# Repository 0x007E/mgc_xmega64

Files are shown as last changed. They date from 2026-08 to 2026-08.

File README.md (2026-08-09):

  

# `MGC_module` - ATxmega64

The `ATxmega64` (`mgc_module`) is an adaptable board for the [MeGARCard](https://github.com/0x007e/mgc). The board offers the possibility to control the `MeGARCard` with an [ATxmega64](#additional-information). The board itself is connected to the `MeGARCard` within the pcb-to-pcb connectors (no soldering necessary). With the onboard dip-switches the reset can be enabled/disabled for `PDI` programming.

> To mount the board on the `MeGARCard` disconnect the power source (`USB-C` connector) or any other used source from the MeGARCard!

| Experience  | Level |
|:---|:---:|
| Soldering | ?% |

# Downloads

| Type | File | Description |
|:---:|:---:|:---|
| Schematic | [pdf](https://github.com/0x007E/mgc_xmega64/releases/latest/download/schematic.pdf) / [cadlab](https://cadlab.io/project/30510/main/files) | Schematic files |
| Board | [pdf](https://github.com/0x007E/mgc_xmega64/releases/latest/download/pcb.pdf) / [cadlab](https://cadlab.io/project/30510/main/files) | Board file |
| Drill | [pdf](https://github.com/0x007E/mgc_xmega64/releases/latest/download/drill.pdf) | Drill file |
| BoM | [xlsx](https://github.com/0x007E/mgc_xmega64/releases/latest/download/bom.xlsx) / [html](https://github.com/0x007E/mgc_xmega64/releases/latest/download/ibom.html) | Bill of Material as Excel/interactive HTML |
| PCB | [zip](https://github.com/0x007E/mgc_xmega64/releases/latest/download/kicad.zip) / [tar](https://github.com/0x007E/mgc_xmega64/releases/latest/download/kicad.tar.gz) | KiCAD/Gerber/BoM/Drill files |

# Hardware

The pcb is created with `KiCAD`. All files are built with `github actions` so that they are ready for a production environment.

## PCB

The circuit board is populated on both sides (Top, Bottom). The best way for soldering the `SMD` components is within a vapor phase soldering system and for the `THT` components with a standard soldering system.

### Top Layer

Top Layer

### Bottom Layer

Bottom Layer

# Additional Information

| Type | Link | Description |
|:---:|:---:|:---|
| ATxmega64  | [pdf](https://ww1.microchip.com/downloads/en/DeviceDoc/ATxmega128-64-32-16A4U-DataSheet-DS40002166A.pdf) | ATxmega16/32/64/128 Data Sheet |

---

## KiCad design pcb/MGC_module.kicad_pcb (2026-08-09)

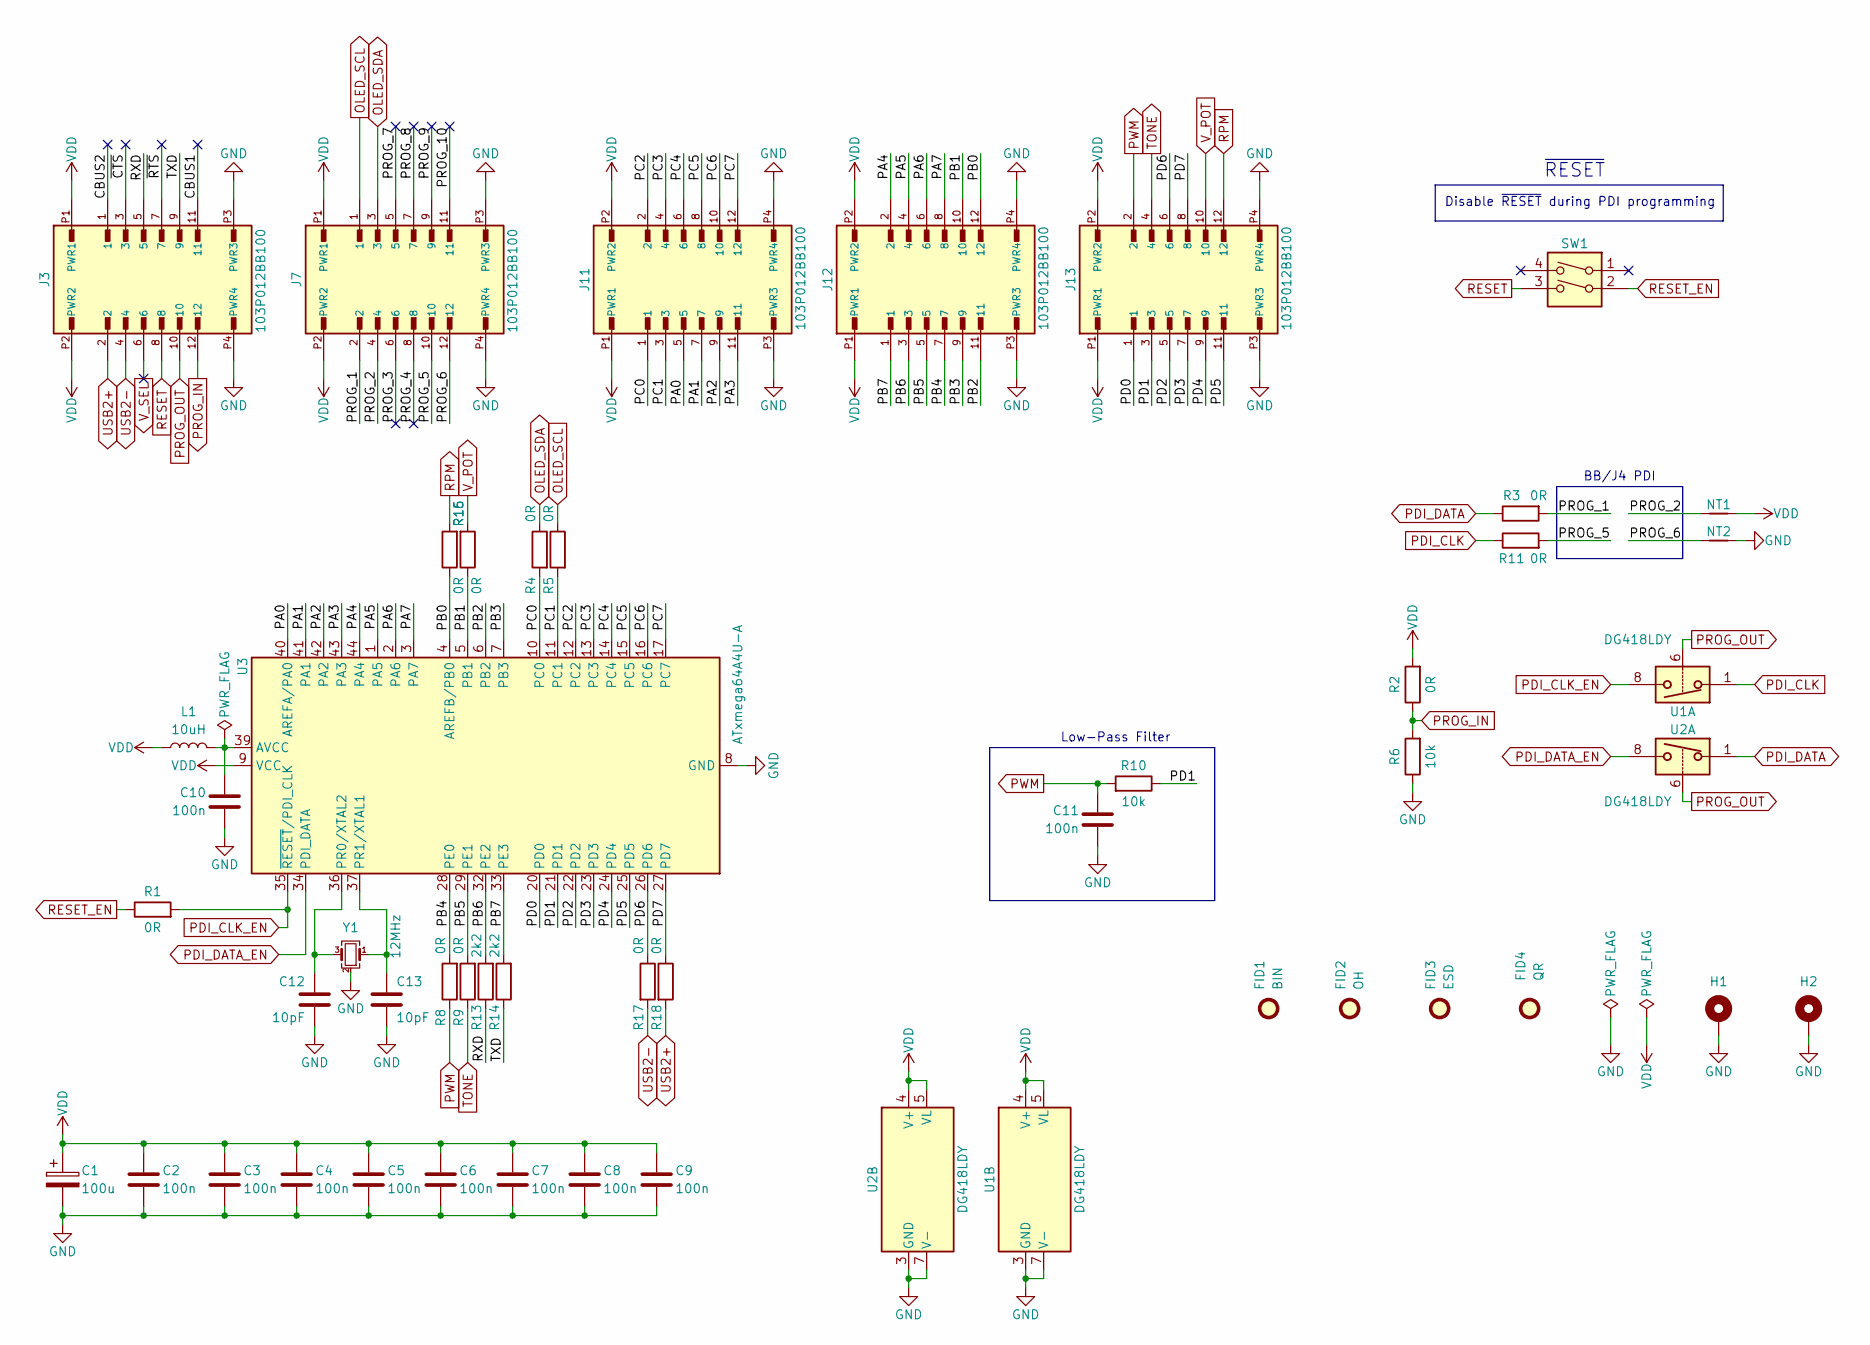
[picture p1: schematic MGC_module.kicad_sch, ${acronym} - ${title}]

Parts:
C1: 100u; CP_EIA-3528-21_Kemet-B; DigiKey 478-3877-1-ND
C2, C3, C4, C5, C6, C7, C8, C9, C10, C11: 100n; C_1206_3216Metric
C12, C13: 10pF; C_0603_1608Metric
FID1: BIN; WEEE-Logo_4.2x6mm_SilkScreen
FID2: OH; OSHW-Logo2_7.3x6mm_SilkScreen
FID3: ESD; ESD-Logo_6.6x6mm_SilkScreen
FID4: QR; QR_0x007e_very_small
H1, H2: MountingHole_Pad; MountingHole_2.7mm_M2.5_DIN965_Pad
J3, J7, J11, J12, J13: 103P012BB100; AMPHENOL_103P012BB100; DigiKey 609-103P012BB100CT-ND
L1: 10uH; L_1206_3216Metric
NT1, NT2: NetTie_2; NetTie-2_SMD_Pad0.5mm
R1, R2, R3, R4, R5, R8, R9, R11, R15, R16: 0R; R_1206_3216Metric
R6, R10: 10k; R_1206_3216Metric
R13, R14: 2k2; R_1206_3216Metric
R17, R18: 0R; R_0603_1608Metric; DigiKey CR0603AJ/-000EASCT-ND
SW1: SW_DIP_x02; SW_DIP_SPSTx02_Slide_6.7x6.64mm_W6.73mm_P2.54mm_LowProfile_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
U1, U2: DG418LDY; SOIC-8_3.9x4.9mm_P1.27mm; DigiKey DG417LEDY-T1-GE4CT-ND
U3: ATxmega64A4U-A; TQFP-44_10x10mm_P0.8mm; DigiKey ATXMEGA64A4U-AU-ND
Y1: 12MHz; Crystal_SMD_Abracon_ABM8AIG-4Pin_3.2x2.5mm

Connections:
/CBUS1: J3.11
/CBUS2: J3.1
/PA0: J11.5, U3.40 (AREFA/PA0)
/PA1: J11.7, U3.41 (PA1)
/PA2: J11.9, U3.42 (PA2)
/PA3: J11.11, U3.43 (PA3)
/PA4: J12.2, U3.44 (PA4)
/PA5: J12.4, U3.1 (PA5)
/PA6: J12.6, U3.2 (PA6)
/PA7: J12.8, U3.3 (PA7)
/PB0: J12.12, R15.1, U3.4 (AREFB/PB0)
/PB1: J12.10, R16.1, U3.5 (PB1)
/PB2: J12.11, U3.6 (PB2)
/PB3: J12.9, U3.7 (PB3)
/PB4: J12.7, R8.2, U3.28 (PE0)
/PB5: J12.5, R9.2, U3.29 (PE1)
/PB6: J12.3, R13.2, U3.32 (PE2)
/PB7: J12.1, R14.2, U3.33 (PE3)
/PC0: J11.1, R4.2, U3.10 (PC0)
/PC1: J11.3, R5.2, U3.11 (PC1)
/PC2: J11.2, U3.12 (PC2)
/PC3: J11.4, U3.13 (PC3)
/PC4: J11.6, U3.14 (PC4)
/PC5: J11.8, U3.15 (PC5)
/PC6: J11.10, U3.16 (PC6)
/PC7: J11.12, U3.17 (PC7)
/PD0: J13.1, U3.20 (PD0)
/PD1: J13.3, R10.1, U3.21 (PD1)
/PD2: J13.5, U3.22 (PD2)
/PD3: J13.7, U3.23 (PD3)
/PD4: J13.9, U3.24 (PD4)
/PD5: J13.11, U3.25 (PD5)
/PD6: J13.6, R17.1, U3.26 (PD6)
/PD7: J13.8, R18.1, U3.27 (PD7)
/PROG_1: J7.2, R3.2
/PROG_2: J7.4, NT1.1
/PROG_3: J7.6
/PROG_4: J7.8
/PROG_5: J7.10, R11.2
/PROG_6: J7.12, NT2.1
/PROG_7: J7.5
/PROG_8: J7.7
/PROG_9: J7.9
/PROG_10: J7.11
/RXD: J3.5, R13.1
/TXD: J3.9, R14.1
/~CTS: J3.3
/~RTS: J3.7
GND: C1.2, C2.2, C3.2, C4.2, C5.2, C6.2, C7.2, C8.2, C9.2, C10.2, C11.2, C12.2, C13.2, H1.1, H2.1, J3.P3 (PWR3), J3.P4 (PWR4), J7.P3 (PWR3), J7.P4 (PWR4), J11.P3 (PWR3), J11.P4 (PWR4), J12.P3 (PWR3), J12.P4 (PWR4), J13.P3 (PWR3), J13.P4 (PWR4), NT2.2, R6.1, U1.3 (GND), U1.7 (V-), U2.3 (GND), U2.7 (V-), U3.8 (GND), U3.18 (GND), U3.30 (GND), U3.38 (GND), Y1.2 (G), Y1.4 (G)
unnamed: C10.1, L1.2, U3.39 (AVCC)
unnamed: C12.1, U3.36 (PR0/XTAL2), Y1.3
unnamed: C13.1, U3.37 (PR1/XTAL1), Y1.1
OLED_SCL: J7.1, R5.1
OLED_SDA: J7.3, R4.1
PDI_CLK: R11.1, U1.1
PDI_CLK_EN: R1.2, U1.8, U3.35 (~RESET/PDI_CLK)
PDI_DATA: R3.1, U2.1
PDI_DATA_EN: U2.8, U3.34 (PDI_DATA)
PROG_IN: J3.12, R2.1, R6.2
PROG_OUT: J3.10, U1.6, U2.6
PWM: C11.1, J13.2, R8.1, R10.2
RESET: J3.8, SW1.3
RESET_EN: R1.1, SW1.2
RPM: J13.12, R15.2
TONE: J13.4, R9.1
USB2+: J3.2, R18.2
USB2-: J3.4, R17.2
VDD: C1.1, C2.1, C3.1, C4.1, C5.1, C6.1, C7.1, C8.1, C9.1, J3.P1 (PWR1), J3.P2 (PWR2), J7.P1 (PWR1), J7.P2 (PWR2), J11.P1 (PWR1), J11.P2 (PWR2), J12.P1 (PWR1), J12.P2 (PWR2), J13.P1 (PWR1), J13.P2 (PWR2), L1.1, NT1.2, R2.2, U1.4 (V+), U1.5 (VL), U2.4 (V+), U2.5 (VL), U3.9 (VCC), U3.19 (VCC), U3.31 (VCC)
V_POT: J13.10, R16.2
V_SEL: J3.6

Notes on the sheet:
Disable ~{RESET} during PDI programming
Low-Pass Filter
BB/J4 PDI
~{RESET}

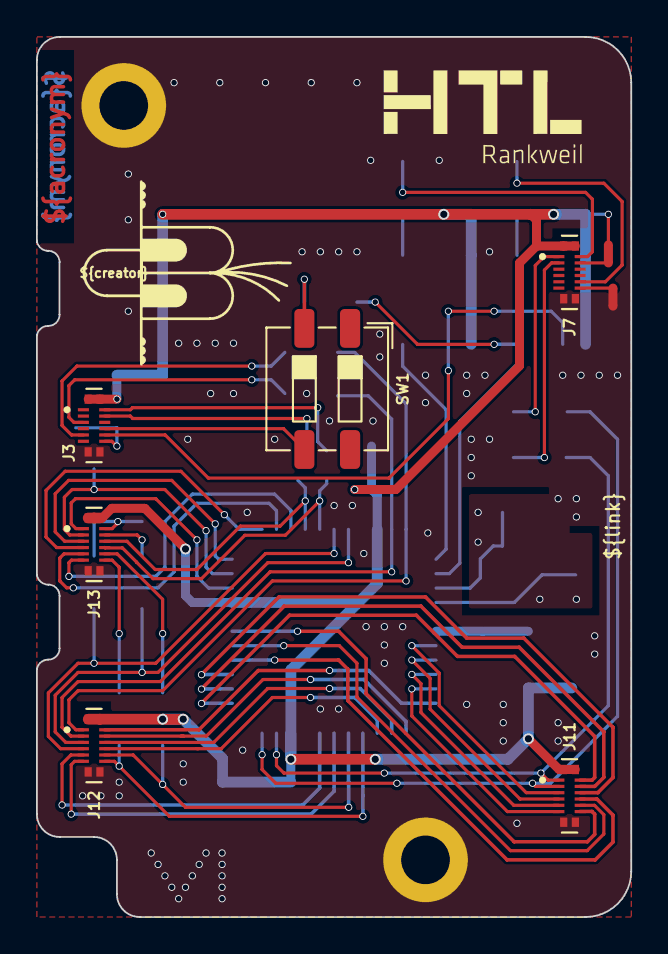
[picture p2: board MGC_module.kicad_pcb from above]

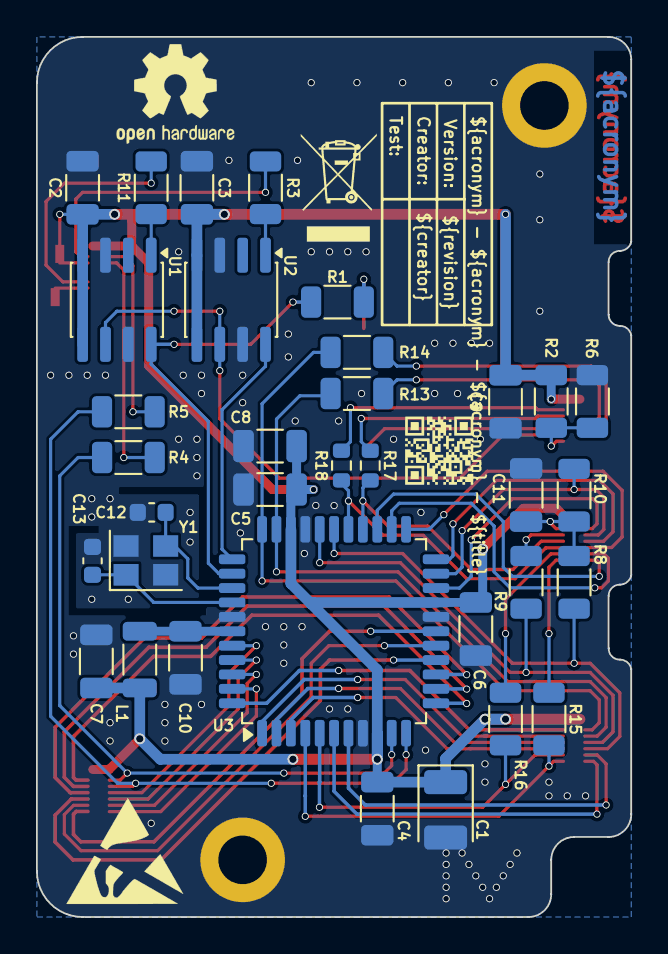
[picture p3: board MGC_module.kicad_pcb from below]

Board: 2 copper layers, 33.0 x 48.9 mm, 48 parts (38 on the bottom side), 59 nets.

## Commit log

2026-08-09 Add pcb layout
    [MGC_module.kicad_pcb, MGC_module.kicad_sch]
2026-08-09 Optimize fabrication layer
    [MGC_module.kicad_pcb]

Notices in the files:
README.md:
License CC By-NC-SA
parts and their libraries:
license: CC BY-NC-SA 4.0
